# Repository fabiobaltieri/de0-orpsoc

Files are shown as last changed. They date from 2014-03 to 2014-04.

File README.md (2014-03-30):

DE0 ORPSoC
==========

This project is an addon I/O board for the Altera DE0-Nano.  It is meant to
be used as a development platform for the OpenRISC soft CPU.

The peripherals on the board are:

* Dual USB to UART
* RMII Ethernet
* SPI Ethernet
* RTC w/ battery backup (I2C)
* Thermal sensor (I2C)
* Micro SD card
* USB 1.1 Transceiver
* Reset button
* Status LEDs

All devices are powered at 3.3V from the DE0 regulators, though a set of
jumpers allow to power the DE0 itself from one of the USB ports of the I/O
board.

License
-------

This work is licensed under a Creative Commons Attribution-ShareAlike 3.0
License.

Contents
--------

    README      this file
    hardware/   source directory for the hardware design

Hardware
--------

All hardware files (schematic, layout and libraries) are in CadSoft Eagle
format.

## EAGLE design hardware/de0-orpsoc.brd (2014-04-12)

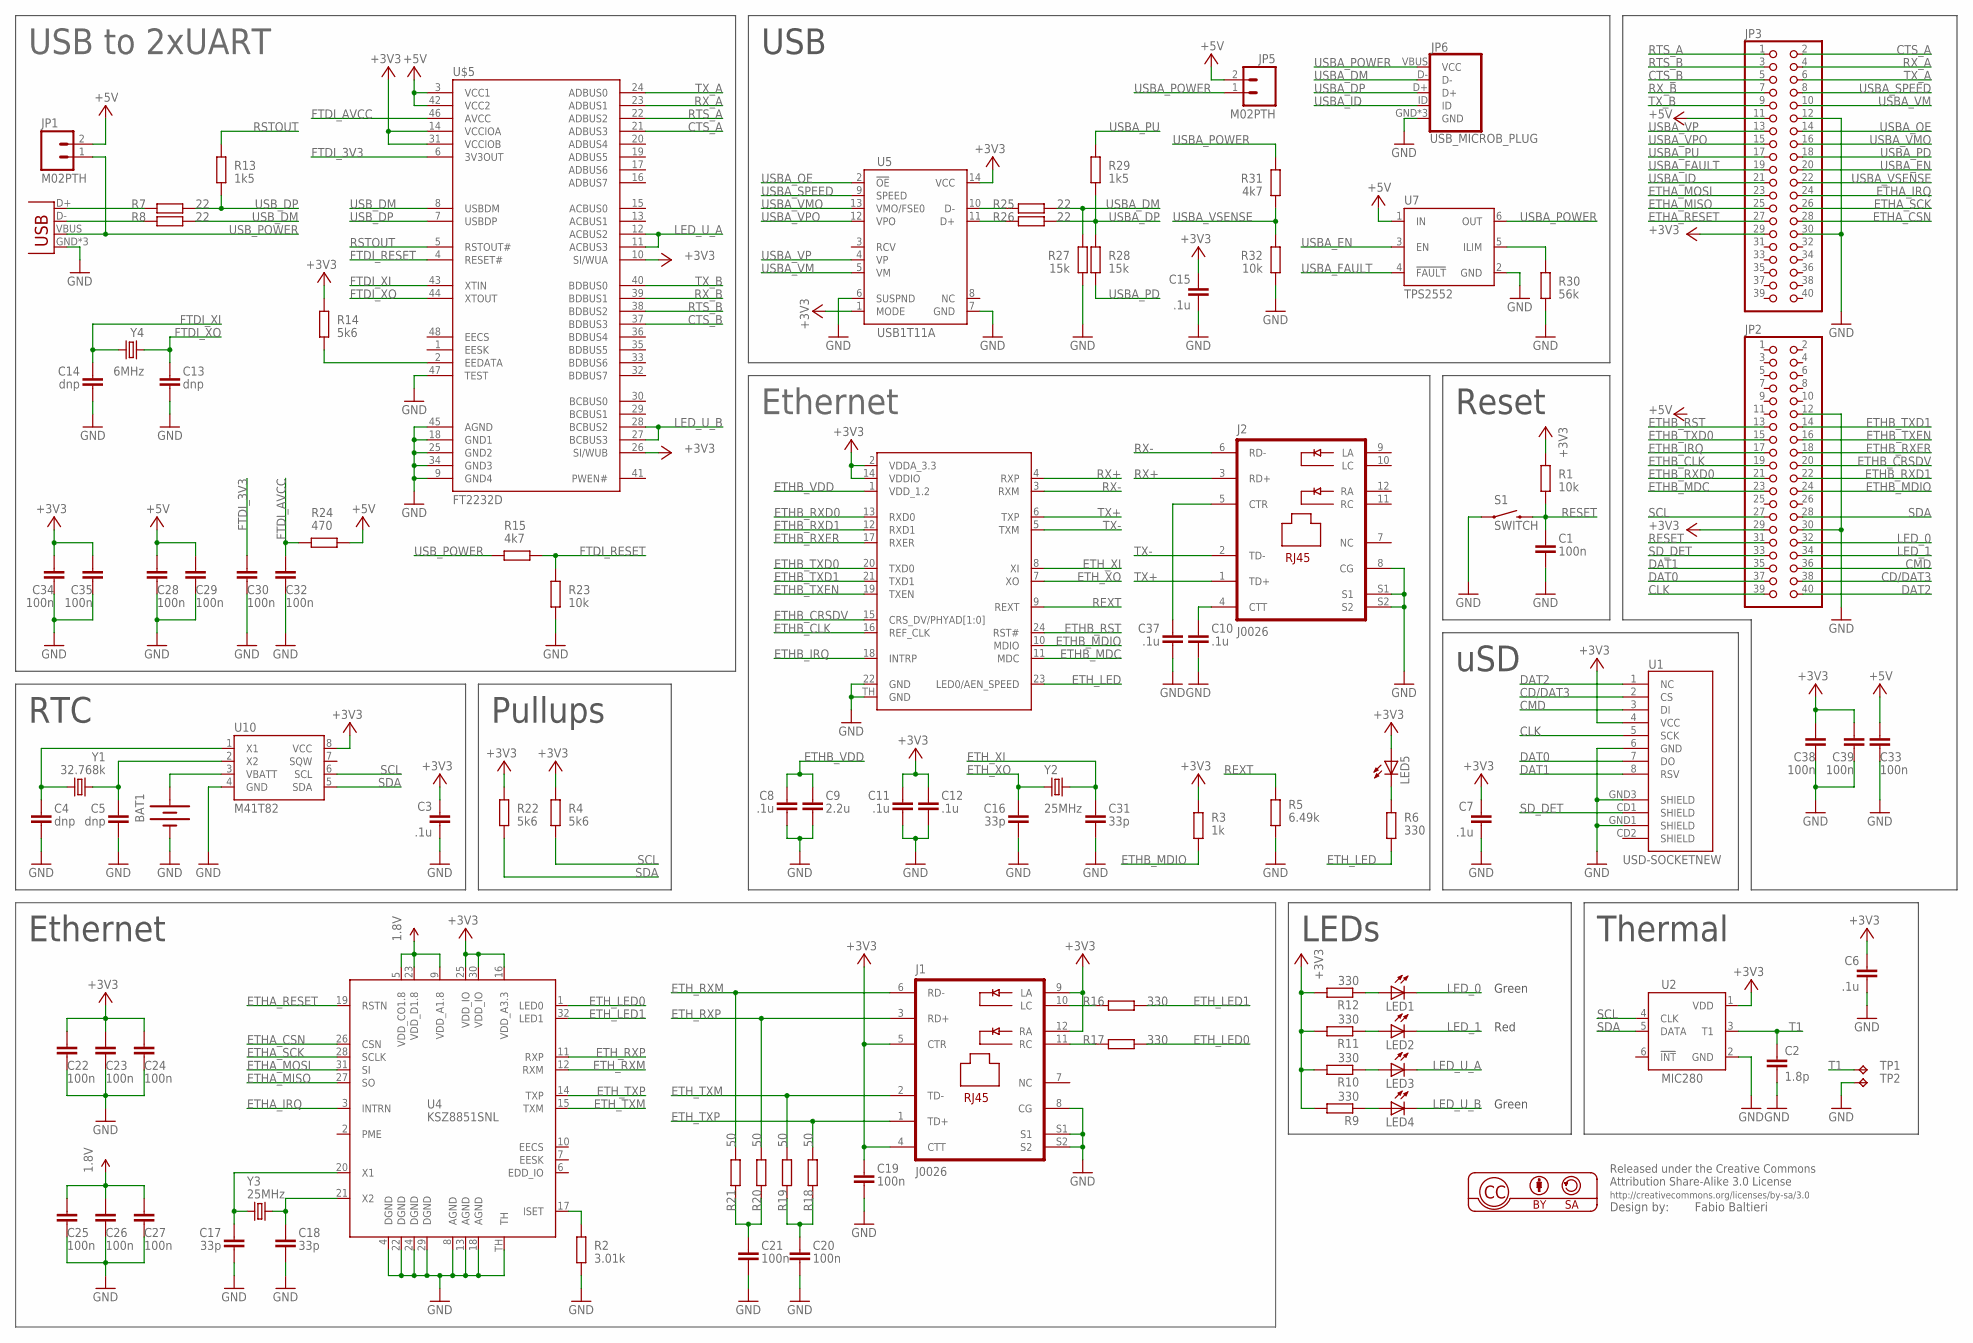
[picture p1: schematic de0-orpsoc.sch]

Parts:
BAT1: BATTERY12PTH; BATTCON_12MM_PTH
C1, C19, C20, C21, C22, C23, C24, C25, C26, C27, C28, C29, C30, C32, C33, C34, C35, C38, C39: 100n; C0603
C2: 1.8p; C0603
C3, C6, C7, C8, C10, C11, C12, C15, C37: .1u; C0603
C4, C5, C13, C14: dnp; C0603
C9: 2.2u; C0603
C16, C17, C18, C31: 33p; C0603
J1, J2: J0026; PJ-J0
JP1, JP5: M02PTH; 1X02
JP2, JP3: PINHD-2X20; 2X20
JP6: USB_MICROB_PLUG; USB-MICROB
JP10: USB-MICROB
LED1, LED2, LED3, LED4, LED5: LEDCHIPLED_0805; CHIPLED_0805
R1, R23, R32: 10k; R0603
R2: 3.01k; R0603
R3: 1k; R0603
R4, R14, R22: 5k6; R0603
R5: 6.49k; R0603
R6, R9, R10, R11, R12, R16, R17: 330; R0603
R7, R8, R25, R26: 22; R0603
R13, R29: 1k5; R0603
R15, R31: 4k7; R0603
R18, R19, R20, R21: 50; R0603
R24: 470; R0603
R27, R28: 15k; R0603
R30: 56k; R0603
S1: SWITCH; TACTILE_SWITCH_SMD
TP1, TP2: TPTP12R; TP12R
U1: USD-SOCKETNEW; MICRO-SD-SOCKET-PP
U2: MIC280; SOT23-6L
U3: KSZ8081RNA; QFN24
U4: KSZ8851SNL; MLF32-TH
U5: USB1T11A; SOIC14
U7: TPS2552; SOT23-6L
U10: M41T82; SO08
U$5: FT2232D; LQFP-48
Y1: 32.768k; CRYSTAL-32KHZ-SMD
Y2, Y3: 25MHz; CRYSTAL-SMD-5X3
Y4: 6MHz; CRYSTAL-SMD-5X3

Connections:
1.8V: C25.1, C26.1, C27.1, U4.5 (VDD_CO1.8), U4.9 (VDD_A1.8), U4.23 (VDD_D1.8)
+3V3: C3.1, C6.1, C7.1, C11.1, C12.1, C15.1, C19.1, C22.1, C23.1, C24.1, C34.1, C35.1, C38.1, C39.1, J1.4 (CTT), J1.5 (CTR), J1.9 (LA), J1.12 (RA), JP2.29, JP3.29, LED5.A, R1.2, R3.2, R4.1, R9.2, R10.2, R11.2, R12.2, R14.1, R22.1, U1.4 (VCC), U2.1 (VDD), U3.2 (VDDA_3.3), U3.14 (VDDIO), U4.16 (VDD_A3.3), U4.25 (VDD_IO), U4.30 (VDD_IO), U5.1 (MODE), U5.14 (VCC), U10.8 (VCC), U$5.10 (SI/WUA), U$5.14 (VCCIOA), U$5.26 (SI/WUB), U$5.31 (VCCIOB)
+5V: C28.1, C29.1, C33.1, JP1.2, JP3.11, JP5.2, R24.2, U7.1 (IN), U$5.3 (VCC1), U$5.42 (VCC2)
CD/DAT3: JP2.38, U1.2 (CS)
CLK: JP2.39, U1.5 (SCK)
CMD: JP2.36, U1.3 (DI)
CTS_A: JP3.2, U$5.21 (ADBUS3)
CTS_B: JP3.5, U$5.37 (BDBUS3)
DAT0: JP2.37, U1.7 (DO)
DAT1: JP2.35, U1.8 (RSV)
DAT2: JP2.40, U1.1 (NC)
ETHA_CSN: JP3.28, U4.26 (CSN)
ETHA_IRQ: JP3.24, U4.3 (INTRN)
ETHA_MISO: JP3.25, U4.27 (SO)
ETHA_MOSI: JP3.23, U4.31 (SI)
ETHA_RESET: JP3.27, U4.19 (RSTN)
ETHA_SCK: JP3.26, U4.28 (SCLK)
ETHB_CLK: JP2.19, U3.16 (REF_CLK)
ETHB_CRSDV: JP2.20, U3.15 (CRS_DV/PHYAD[1:0])
ETHB_IRQ: JP2.17, U3.18 (INTRP)
ETHB_MDC: JP2.23, U3.11 (MDC)
ETHB_MDIO: JP2.24, R3.1, U3.10 (MDIO)
ETHB_RST: JP2.13, U3.24 (RST#)
ETHB_RXD0: JP2.21, U3.13 (RXD0)
ETHB_RXD1: JP2.22, U3.12 (RXD1)
ETHB_RXER: JP2.18, U3.17 (RXER)
ETHB_TXD0: JP2.15, U3.20 (TXD0)
ETHB_TXD1: JP2.14, U3.21 (TXD1)
ETHB_TXEN: JP2.16, U3.19 (TXEN)
ETHB_VDD: C8.1, C9.1, U3.1 (VDD_1.2)
ETH_LED: R6.1, U3.23 (LED0/AEN_SPEED)
ETH_LED0: R17.2, U4.1 (LED0)
ETH_LED1: R16.2, U4.32 (LED1)
ETH_RXM: J1.6 (RD-), R21.2, U4.12 (RXM)
ETH_RXP: J1.3 (RD+), R20.2, U4.11 (RXP)
ETH_TXM: J1.2 (TD-), R19.2, U4.15 (TXM)
ETH_TXP: J1.1 (TD+), R18.2, U4.14 (TXP)
ETH_XI: C31.1, U3.8 (XI), Y2.3 (2)
ETH_XO: C16.1, U3.7 (XO), Y2.1
FTDI_3V3: C30.1, U$5.6 (3V3OUT)
FTDI_AVCC: C32.1, R24.1, U$5.46 (AVCC)
FTDI_RESET: R15.2, R23.1, U$5.4 (RESET#)
FTDI_XI: C14.1, U$5.43 (XTIN), Y4.3 (2)
FTDI_XO: C13.1, U$5.44 (XTOUT), Y4.1
GND: BAT1.GND (-), C1.2, C2.2, C3.2, C4.2, C5.2, C6.2, C7.2, C8.2, C9.2, C10.2, C11.2, C12.2, C13.2, C14.2, C15.2, C16.2, C17.2, C18.2, C19.2, C20.2, C21.2, C22.2, C23.2, C24.2, C25.2, C26.2, C27.2, C28.2, C29.2, C30.2, C31.2, C32.2, C33.2, C34.2, C35.2, C37.2, C38.2, C39.2, J1.8 (CG), J1.S1, J1.S2, J2.8 (CG), J2.S1, J2.S2, JP2.12, JP2.30, JP3.12, JP3.30, JP6.GND, JP6.MT1 (GND), JP6.MT2 (GND), JP10.GND, JP10.MT1 (GND), JP10.MT2 (GND), R2.2, R5.1, R23.2, R27.2, R30.2, R32.2, S1.1, TP2.TP, U1.6 (GND), U1.GND1 (SHIELD), U1.GND3 (SHIELD), U2.2 (GND), U3.22 (GND), U3.TH (GND), U4.4 (DGND), U4.8 (AGND), U4.13 (AGND), U4.18 (AGND), U4.22 (DGND), U4.24 (DGND), U4.29 (DGND), U4.TH, U5.6 (SUSPND), U5.7 (GND), U7.2 (GND), U10.4 (GND), U$5.9 (GND4), U$5.18 (GND1), U$5.25 (GND2), U$5.34 (GND3), U$5.45 (AGND), U$5.47 (TEST)
LED_0: JP2.32, LED1.C
LED_1: JP2.34, LED2.C
LED_U_A: LED3.C, U$5.11 (ACBUS3), U$5.12 (ACBUS2)
LED_U_B: LED4.C, U$5.27 (BCBUS3), U$5.28 (BCBUS2)
unnamed: LED3.A, R10.1
unnamed: LED4.A, R9.1
unnamed: C5.1, U10.2 (X2), Y1.X1 (1)
unnamed: BAT1.VCC@1 (+), U10.3 (VBATT)
unnamed: C4.1, U10.1 (X1), Y1.X2 (2)
unnamed: LED5.C, R6.2
unnamed: JP10.D-, R8.1
unnamed: C10.1, J2.4 (CTT)
unnamed: C37.1, J2.5 (CTR)
unnamed: R25.1, U5.10 (D-)
unnamed: JP10.D+, R7.1
unnamed: R26.1, U5.11 (D+)
unnamed: R14.2, U$5.2 (EEDATA)
unnamed: R30.1, U7.5 (ILIM)
unnamed: LED1.A, R12.1
unnamed: LED2.A, R11.1
unnamed: J1.10 (LC), R16.1
unnamed: J1.11 (RC), R17.1
unnamed: R2.1, U4.17 (ISET)
unnamed: C17.1, U4.20 (X1), Y3.1
unnamed: C18.1, U4.21 (X2), Y3.3 (2)
unnamed: C21.1, R20.1, R21.1
unnamed: C20.1, R18.1, R19.1
RESET: C1.1, JP2.31, R1.1, S1.3 (2)
REXT: R5.2, U3.9 (REXT)
RSTOUT: R13.1, U$5.5 (RSTOUT#)
RTS_A: JP3.1, U$5.22 (ADBUS2)
RTS_B: JP3.3, U$5.38 (BDBUS2)
RX+: J2.3 (RD+), U3.4 (RXP)
RX-: J2.6 (RD-), U3.3 (RXM)
RX_A: JP3.4, U$5.23 (ADBUS1)
RX_B: JP3.7, U$5.39 (BDBUS1)
SCL: JP2.27, R4.2, U2.4 (CLK), U10.6 (SCL)
SDA: JP2.28, R22.2, U2.5 (DATA), U10.5 (SDA)
SD_DET: JP2.33, U1.CD1 (SHIELD)
T1: C2.1, TP1.TP, U2.3 (T1)
TX+: J2.1 (TD+), U3.6 (TXP)
TX-: J2.2 (TD-), U3.5 (TXM)
TX_A: JP3.6, U$5.24 (ADBUS0)
TX_B: JP3.9, U$5.40 (BDBUS0)
USBA_DM: JP6.D-, R25.2, R27.1
USBA_DP: JP6.D+, R26.2, R28.1, R29.2
USBA_EN: JP3.20, U7.3 (EN)
USBA_FAULT: JP3.19, U7.4 (!FAULT)
USBA_ID: JP3.21, JP6.ID
USBA_OE: JP3.14, U5.2 (!OE)
USBA_PD: JP3.18, R28.2
USBA_POWER: JP5.1, JP6.VBUS (VCC), R31.1, U7.6 (OUT)
USBA_PU: JP3.17, R29.1
USBA_SPEED: JP3.8, U5.9 (SPEED)
USBA_VM: JP3.10, U5.5 (VM)
USBA_VMO: JP3.16, U5.13 (VMO/FSE0)
USBA_VP: JP3.13, U5.4 (VP)
USBA_VPO: JP3.15, U5.12 (VPO)
USBA_VSENSE: JP3.22, R31.2, R32.1
USB_DM: R8.2, U$5.8 (USBDM)
USB_DP: R7.2, R13.2, U$5.7 (USBDP)
USB_POWER: JP1.1, JP10.VBUS, R15.1

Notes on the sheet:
Ethernet
Reset
LEDs
RTC
Pullups
Thermal
USB to 2xUART
uSD
USB
Red
Green
Green

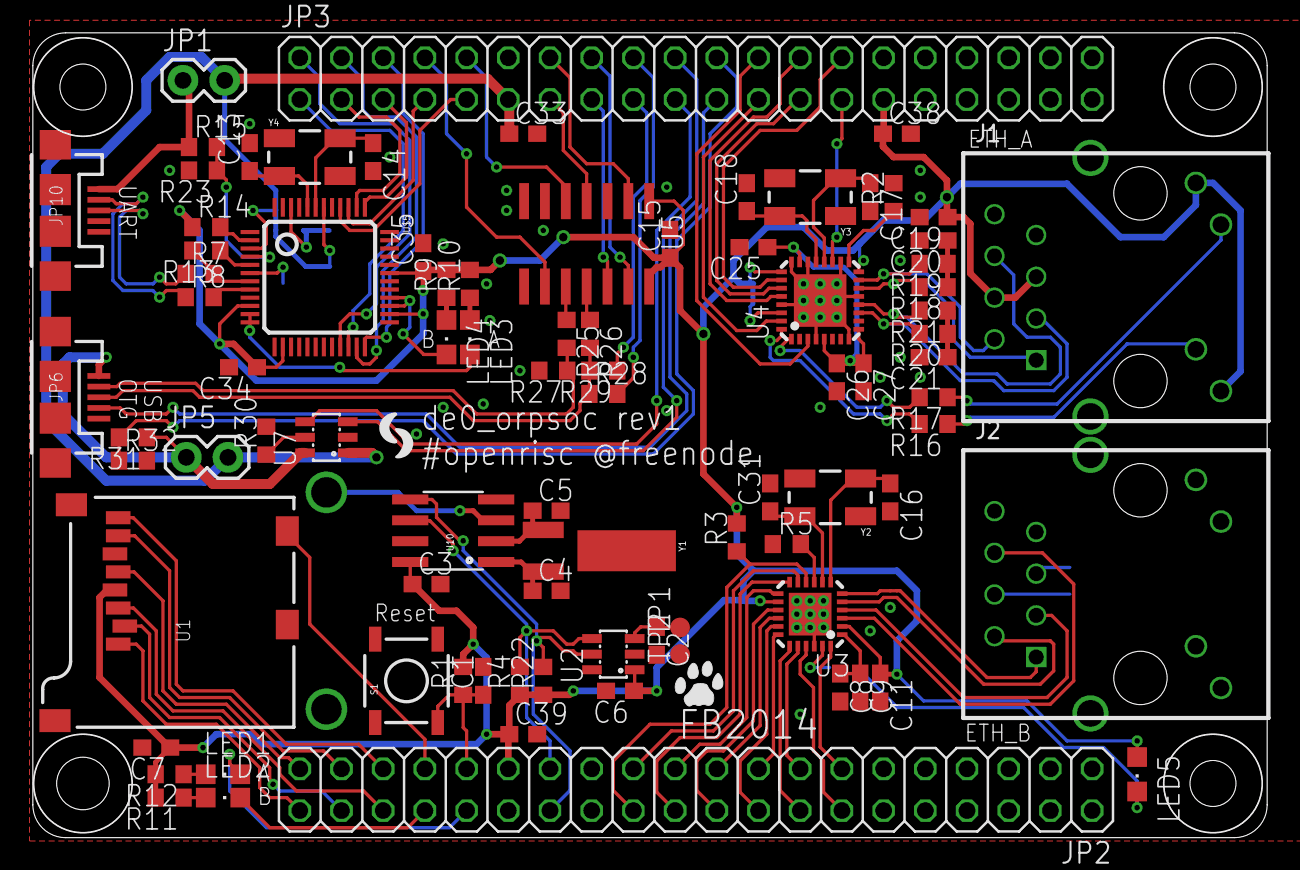
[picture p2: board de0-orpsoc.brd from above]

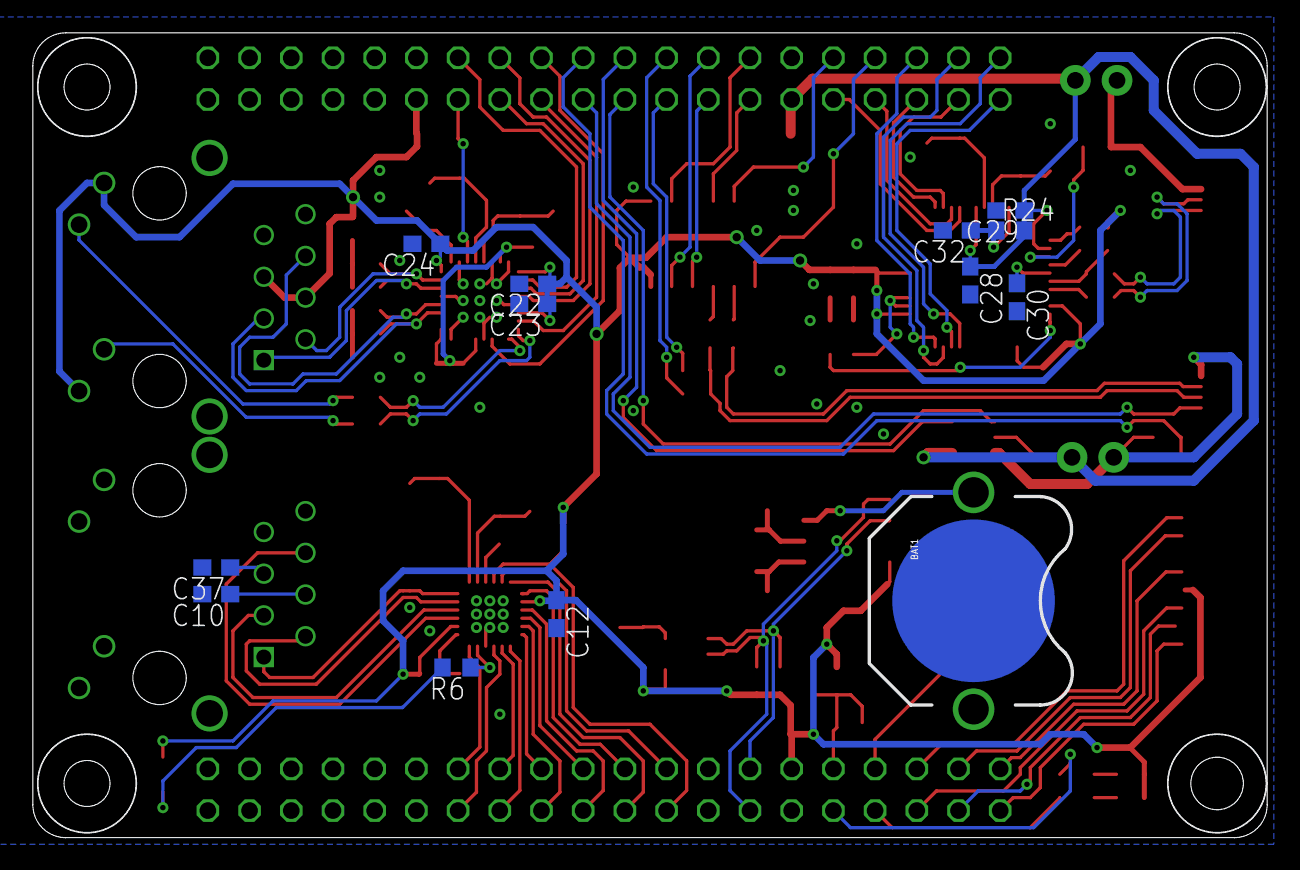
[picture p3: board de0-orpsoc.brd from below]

Board: 2 copper layers, 75.2 x 49.0 mm, 101 parts (13 on the bottom side), 107 nets.

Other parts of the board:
U$1: CAT-L
U$4: CS

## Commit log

2014-03-29 hw: fix osc cap value
    [de0-orpsoc.brd, de0-orpsoc.sch]
2014-03-29 hw: mark a yellow LED
    [de0-orpsoc.sch]
2014-03-30 hw: misc value fixes
    [de0-orpsoc.brd, de0-orpsoc.sch]
2014-04-12 hw: part values tweaks
    [de0-orpsoc.brd, de0-orpsoc.sch]
2014-04-12 hw: change rtc pn
    [de0-orpsoc.brd, de0-orpsoc.sch]

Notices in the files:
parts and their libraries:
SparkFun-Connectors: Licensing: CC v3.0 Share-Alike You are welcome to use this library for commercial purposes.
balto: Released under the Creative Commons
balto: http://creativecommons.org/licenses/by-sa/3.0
